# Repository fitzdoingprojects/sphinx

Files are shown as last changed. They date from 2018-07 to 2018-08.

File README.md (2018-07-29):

# sphinx
Sphinx

## Design Requirements
* Powered from 12V, last minimum one night on charge
* 24 LED Buttons (2 sets of 12)
* Audio Playback with Amplified Sound
* Water and Dust Resistant

## Major Components
* MCU - Teensy 3.6
* Buttons - Momentary Metal Push Buttons
* Sound - Speakers, (amplifier?), Sound Playback Controller
* Power - 12V Battery, step-down converters
* Enclosures - Dust/Water Proof, either acrylic or wood
* Cabling - ???

## Questions
* Buttons are momentary? Size requirements? LED color?
	white, 16mm
* Is there already a battery to use?
	or 12v
* Are there already speakers to use?
	get amazon
* How far are buttons from main controller?
* How far apart are buttons from each other?
* What type of mounting structure is available for main controller?
* Should we bring back-ups of components, if so which ones and how many?

## Design Choices
* Exact button type (see BOM)
* Cabling
	* Should each button have a direct wire back to main controller, or should the main controller route to each fin and then seprate wiring to each button.
	* Use pre-made cables (e.g ethernet cable rj45 to each button, or Parallel Port IEEE 1284 cable to each fin), or custom made cables?
* Speakers
	* Either self powered or amplifer plus unpowered speakers. 
	* How loud? 
	* Full range, or additional subwoofer?
* Power 
	* 12V battery, what size? 
	* How to charge?
* Enclosure
	* What type of material
	* How to mount

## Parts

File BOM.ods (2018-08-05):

Turtle Fortune Teller - Sphinx!
Component | Quantity | Cost | Description | Notes | Link
Teensy 3.6 | 1 | $29.25 | Main MCU |  | https://www.pjrc.com/store/teensy36.html
Audio Adapter Board for Teensy | 1 | $14.25 | Audio Playback controller | Supports up 32gb of files | https://www.pjrc.com/store/teensy3_audio.html
TL5940 | 2 | $2.00 | PWM LED controller | Supports 16 channels, daisy chainable. Works at 5V | http://www.ti.com/product/TLC5940
Buttons (Legitimate) | 27 | $5.00 | Momentary Push Button with LED |  | https://www.sparkfun.com/products/11967
12V to 5V – Converter | 1 | $5.00 | Buck Converter | I already have a couple lying around
Cables
RJ45 8x Port | 3 | $11.00 | Connection Port on main board for 24 buttons/leds |  | https://www.digikey.com/product-detail/en/pulse-electronics-network/E5908-5VC145-L/553-2267-ND/4868937
RJ45 250ft | 1 | $30.00 | RJ45 cable that can be cut to length |  | https://www.monoprice.com/product?p_id=13677
RJ45 Plugs | 2 | $6.00 | Plugs on end of each cable |  | https://www.monoprice.com/product?p_id=7322
RJ45 Strain Relief | 2 | $1.50 | Strain Relief for each Cable |  | https://www.monoprice.com/product?c_id=105&cp_id=10513&cs_id=1051306&p_id=7248&seq=1&format=2
Dust Caps | 3 | $1.00 | Dust Caps for Main board port when cables not connected |  | https://www.ebay.com/itm/Ethernet-Hub-Port-RJ45-Anti-Dust-Cover-Cap-Protector-Plug-10Pcs-Black-CP/332068478418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
Button Sockets | 30 | $1.00 | Sockets for 16” buttons | Requires pig-tie to ethenet cable | https://www.ebay.com/itm/5-Pin-Wire-Connector-Wiring-Socket-Plug-Adapter-For-16-19mm-Push-Button-Switch/272884697047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
Button to Ethernet | 6 | $5.00 | Way to connect Ethernet Cord to Button |  | https://www.adafruit.com/product/1152
Crimp Tool | 1 | $20.00 | Need to crimp cables |  | https://www.amazon.com/TRENDnet-RJ-45-RJ-12-RJ-11-TC-CT68/dp/B0000AZK4G/?tag=823814-20
wire glands
Possible Components
Self Powered Speakers | 1 | $49.13 | Waterproof Self Powered speakers | Set of 2. Alternatively could use unpowered speaker and amplifier. | https://www.amazon.com/Pyle-3-5-inch-Waterproof-Bluetooth-PLMR23BBT/dp/B06XCYDRB7?s=electronics
Battery | 1 | $36.98 | 12V 18Ah AGM battery | Any 12V battery with >10Ah should last the a whole night. | https://www.amazon.com/ExpertPower-EXP12180-Rechargeable-Battery-Bolts/dp/B00A82A3RK?s=electronics
Buttons (China) | 24 | $2.00 | Momentary Push Button with LED | Chinisium | https://www.ebay.com/itm/3Pcs-12mm-3V-LED-Metal-Momentary-Push-Button-Switch-1NO-4Pin-Red-Green-Blue/182232000915
Cables | ??? | $20-50 | Not sure of best cable routing
Through Hole Button mounts | 120 | $0.18 | Could make custom board to connect Buttons to Ethernet cables |  | https://www.digikey.com/product-detail/en/keystone-electronics/3534/36-3534-ND/303876
Ethernet Plug | 30 | $0.50 | Could make custom board to connect Buttons to Ethernet cables |  | https://www.digikey.com/product-detail/en/amphenol-fci/54602-908LF/609-1046-ND/1001360
Other Costs
PCB | 1-3 | $5 each plus shipping | Will need one main board, and possibly one distribution board per fin
Small Components | ??? | $20.00 | I might need to order some other electronics components
Enclosures | 1-3 | $20-50 | Need to make dusty/water resistant enclosures for electronics
PURCHASED SO FAR
Component | Quantity | Cost | Date | From
Button to Ethernet | 30 | $1.00 | 07/12/18 | EBAY
MCU + Audio Controller |  | $65.64 | 07/12/18 | PJRC (Teensy)
Buttons | 27 | $139.67 | 07/26/18 | SparkFun
IP67 RJ-45 FeedThrough cable gland - Field Install 10 pack CG-RJ RJ-FT | 30 | 34.8 | 07/29/18 | ebat
heat shirink
0.11” terminals
digikey/arrow/lcsc orders

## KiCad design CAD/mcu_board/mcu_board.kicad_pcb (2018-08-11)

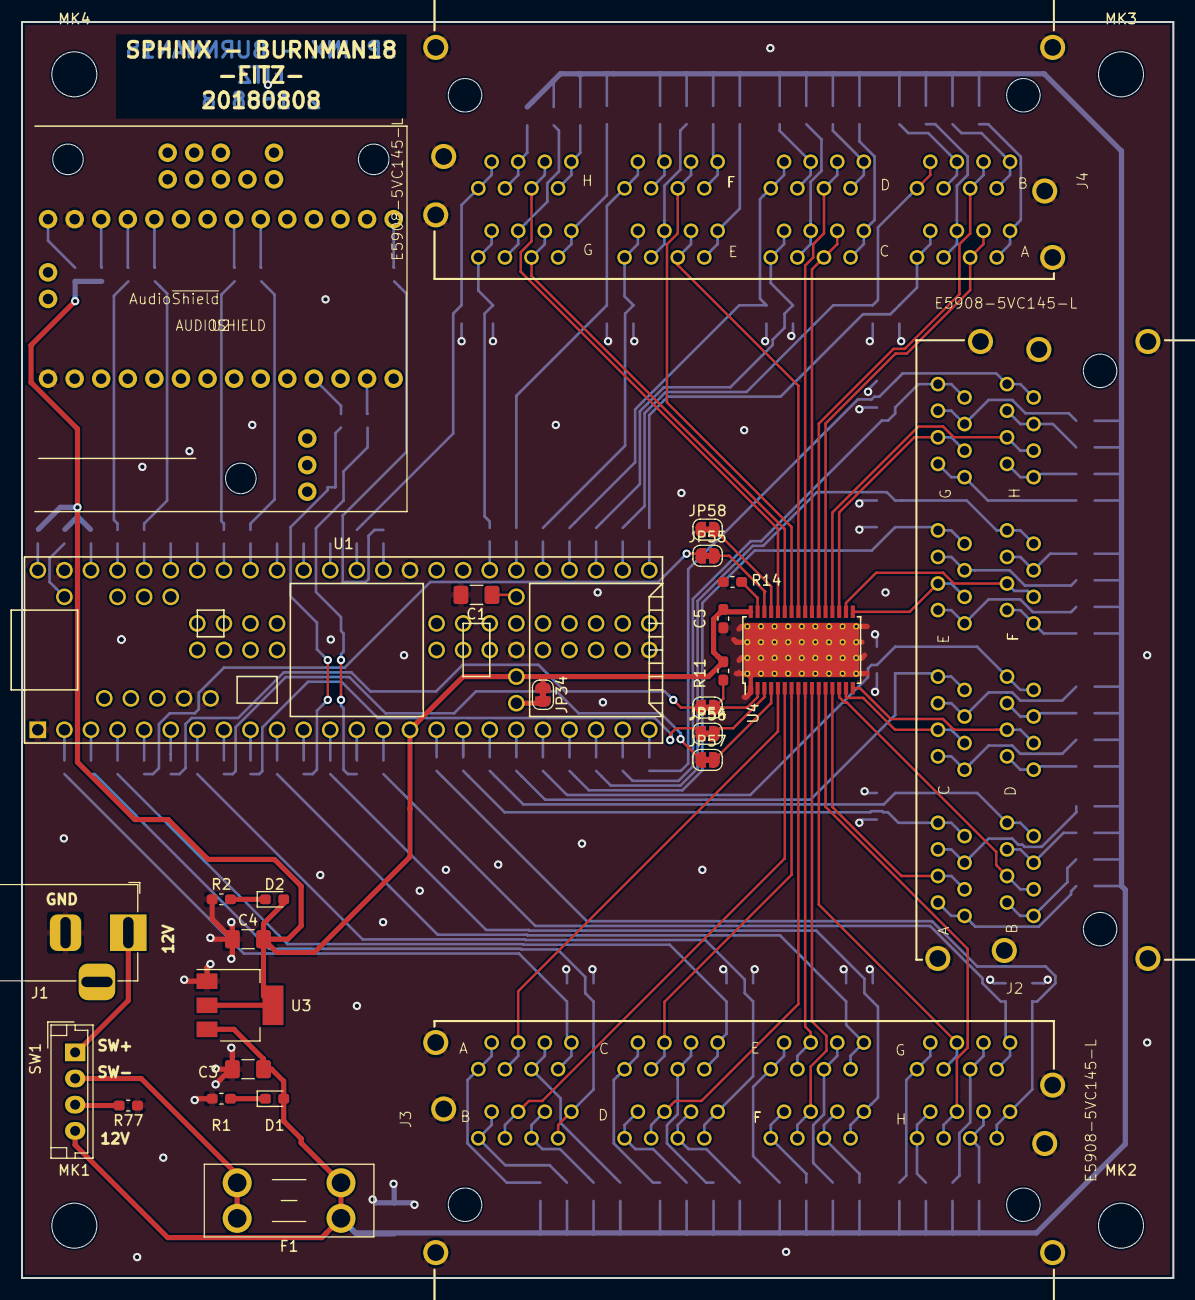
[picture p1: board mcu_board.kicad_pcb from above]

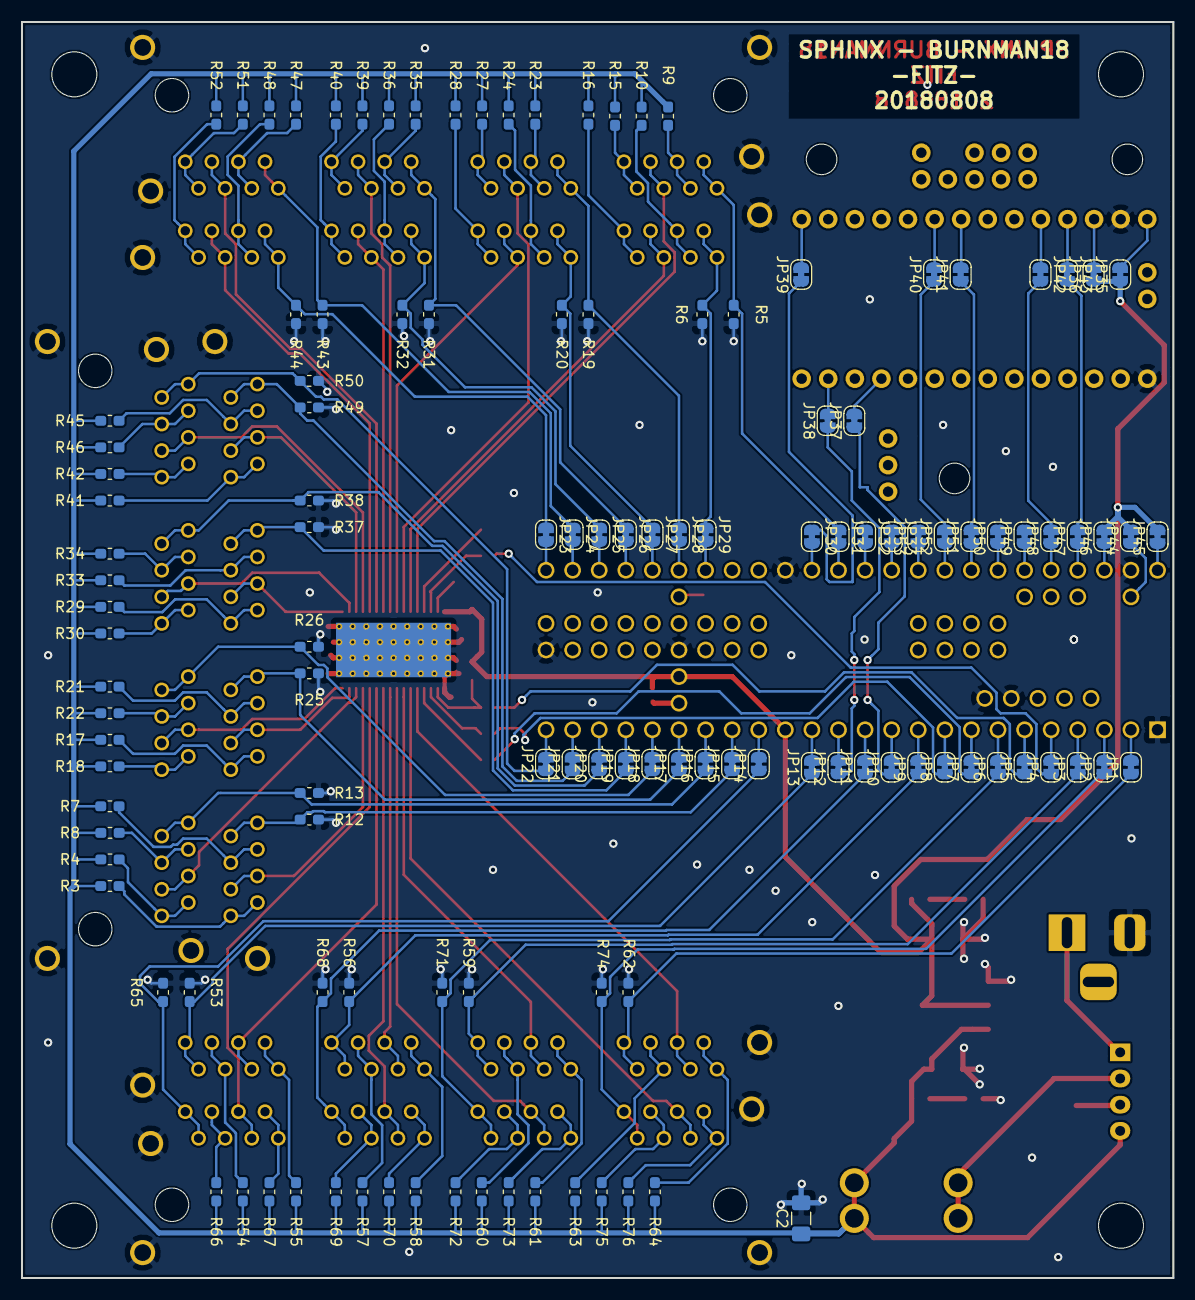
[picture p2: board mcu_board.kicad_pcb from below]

Board: 2 copper layers, 110.0 x 120.0 mm, 156 parts (125 on the bottom side), 175 nets.

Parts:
C1: 0.1uF; C_1206_3216Metric_Pad1.42x1.75mm_HandSolder
C2, C3: 22uF; C_1206_3216Metric_Pad1.42x1.75mm_HandSolder
C4: C_Small; C_1206_3216Metric_Pad1.42x1.75mm_HandSolder
C5: 0.1uF; C_0603_1608Metric_Pad1.05x0.95mm_HandSolder
D1, D2: LED_Small; LED_0603_1608Metric_Pad1.05x0.95mm_HandSolder
F1: Fuse_5A; Fuseholder_Blade_Mini_Keystone_3568
J1: 2.1MM BARREL; BarrelJack_Horizontal
J2, J3, J4: E5908-5VC145-L; PULSE_E5908-5VC145-L
JP1, JP2, JP3, JP4, JP5, JP6, JP7, JP8, JP9, JP10, JP11, JP12, JP13, JP14, JP15, JP16, JP17, JP18, JP19, JP20, JP21, JP22, JP23, JP24, JP25, JP26, JP27, JP28, JP29, JP30, JP31, JP32, JP33, JP34, JP35, JP36, JP37, JP38, JP39, JP40, JP41, JP42, JP43, JP44, JP45, JP46, JP47, JP48, JP49, JP50, JP51, JP52, JP53: Jumper_NO_Small; SolderJumper-2_P1.3mm_Bridged_RoundedPad1.0x1.5mm
JP54, JP55, JP56, JP57, JP58: Jumper_NC_Small; SolderJumper-2_P1.3mm_Bridged_RoundedPad1.0x1.5mm
MK1, MK2, MK3, MK4: Mounting_Hole; MountingHole_4.3mm_M4
R1, R2, R11, R14: 10K; R_0603_1608Metric_Pad1.05x0.95mm_HandSolder
R3, R4, R5, R6, R12, R13, R16, R17, R18, R19, R20, R25, R26, R28, R29, R31, R32, R37, R38, R39, R40, R41, R43, R44, R49, R50, R51, R52, R53, R55, R56, R58, R59, R61, R62, R64, R65, R68, R70, R71, R73, R74, R76, R77: 1K; R_0603_1608Metric_Pad1.05x0.95mm_HandSolder
R7, R8, R9, R10, R21, R22, R23, R24, R33, R34, R35, R36, R45, R46, R47, R48, R54, R57, R60, R63, R66, R69, R72, R75: 2.7K; R_0603_1608Metric_Pad1.05x0.95mm_HandSolder
R15, R27, R30, R42, R67: R_L; R_0603_1608Metric_Pad1.05x0.95mm_HandSolder
SW1: SW_SPST_LED; JST_EH_B04B-EH-A_1x04_P2.50mm_Vertical
U1: Teensy3.6; Teensy35_36
U2: AUDIOSHIELD
U3: LM1117-ADJ; SOT-223-3_TabPin2
U4: TLC5947DAP; HTSSOP-32-1EP_6.1x11mm_P0.65mm_EP5.2x11mm_Mask4.11x4.36mm_T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

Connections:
+3V3: C4.2, C5.1, D2.2, JP34.1, JP35.1, JP36.1, JP44.2, JP45.2, JP46.2, R11.2, U1.15, U1.26, U3.2, U4.32
+12V: C2.1, C3.1, D1.2, F1.1, R3.2, R4.2, R7.1, R8.1, R9.1, R10.1, R15.2, R16.2, R17.2, R18.2, R21.1, R22.1, R23.1, R24.1, R27.2, R28.2, R29.2, R30.2, R33.1, R34.1, R35.1, R36.1, R39.2, R40.2, R41.2, R42.2, R45.1, R46.1, R47.1, R48.1, R51.2, R52.2, R54.1, R55.2, R57.1, R58.2, R60.1, R61.2, R63.1, R64.2, R66.1, R67.2, R69.1, R70.2, R72.1, R73.2, R75.1, R76.2, SW1.4, U3.3
/AUDIO_BCLK: JP10.1, JP37.1
/AUDIO_LRCLK: JP43.2, JP47.2
/AUDIO_MCLK: JP12.1, JP38.1
/AUDIO_RX: JP30.1, JP39.1
/AUDIO_SCL: JP41.1, JP51.2
/AUDIO_SDA: JP40.1, JP52.2
/AUDIO_TX: JP42.2, JP48.2
/BLANK: JP5.1, JP54.1
/LED_0: J4.A5, J4.A6, U4.21
/LED_1: J4.B3, J4.B4, U4.22
/LED_2: J4.C5, J4.C6, U4.23
/LED_3: J4.D3, J4.D4, U4.24
/LED_4: J4.E5, J4.E6, U4.25
/LED_5: J4.F3, J4.F4, U4.26
/LED_6: J4.G5, J4.G6, U4.27
/LED_7: J4.H3, J4.H4, U4.28
/LED_8: J2.A5, J2.A6, U4.13
/LED_9: J2.B3, J2.B4, U4.14
/LED_10: J2.C5, J2.C6, U4.15
/LED_11: J2.D3, J2.D4, U4.16
/LED_12: J2.E5, J2.E6, U4.17
/LED_13: J2.F3, J2.F4, U4.18
/LED_14: J2.G5, J2.G6, U4.19
/LED_15: J2.H3, J2.H4, U4.20
/LED_16: J3.A5, J3.A6, U4.5
/LED_17: J3.B3, J3.B4, U4.6
/LED_18: J3.C5, J3.C6, U4.7
/LED_19: J3.D3, J3.D4, U4.8
/LED_20: J3.E5, J3.E6, U4.9
/LED_21: J3.F3, J3.F4, U4.10
/LED_22: J3.G5, J3.G6, U4.11
/LED_23: J3.H3, J3.H4, U4.12
/SCLK: JP8.1, JP56.1
/SIN: JP7.1, JP57.1
/SW_0: J4.A1, J4.A2, JP23.1, R44.2
/SW_1: J4.B7, J4.B8, JP24.1, R43.2
/SW_2: J4.C1, J4.C2, JP25.1, R32.2
/SW_3: J4.D7, J4.D8, JP26.1, R31.2
/SW_4: J4.E1, J4.E2, JP27.1, R20.2
/SW_5: J4.F7, J4.F8, JP28.1, R19.2
/SW_6: J4.G1, J4.G2, JP29.1, R6.2
/SW_7: J4.H7, J4.H8, JP31.1, R5.2
/SW_8: J2.A1, J2.A2, JP15.1, R12.2
/SW_9: J2.B7, J2.B8, JP16.1, R13.2
/SW_10: J2.C1, J2.C2, JP17.1, R25.2
/SW_11: J2.D7, J2.D8, JP18.1, R26.2
/SW_12: J2.E1, J2.E2, JP19.1, R37.2
/SW_13: J2.F7, J2.F8, JP20.1, R38.2
/SW_14: J2.G1, J2.G2, JP21.1, R49.2
/SW_15: J2.H7, J2.H8, JP22.1, R50.2
/SW_16: J3.A1, J3.A2, JP1.1, R62.2
/SW_17: J3.B7, J3.B8, JP2.1, R74.2
/SW_18: J3.C1, J3.C2, JP3.1, R59.2
/SW_19: J3.D7, J3.D8, JP6.1, R71.2
/SW_20: J3.E1, J3.E2, JP9.1, R56.2
/SW_21: J3.F7, J3.F8, JP11.1, R68.2
/SW_22: J3.G1, J3.G2, JP13.1, R53.2
/SW_23: J3.H7, J3.H8, JP14.1, R65.2
/XLAT: JP4.1, JP55.1
GND: C1.2, C2.2, C3.2, C4.1, C5.2, J1.2, J2.P1, J2.P2, J2.P3, J2.P4, J2.P5, J2.P6, J3.P1, J3.P2, J3.P3, J3.P4, J3.P5, J3.P6, J4.P1, J4.P2, J4.P3, J4.P4, J4.P5, J4.P6, R1.1, R2.1, R5.1, R6.1, R12.1, R13.1, R14.1, R19.1, R20.1, R25.1, R26.1, R31.1, R32.1, R37.1, R38.1, R43.1, R44.1, R49.1, R50.1, R53.1, R56.1, R59.1, R62.1, R65.1, R68.1, R71.1, R74.1, R77.1, U1.1, U1.27, U1.39, U1.52, U1.61, U1.62, U1.74, U2.G, U2.GND, U3.1, U4.1, U4.33
unnamed: C1.1, U1.29
unnamed: D1.1, R1.2
unnamed: D2.1, R2.2
unnamed: F1.2, SW1.2
unnamed: J1.1, SW1.1
unnamed: J2.A3, J2.A4, R7.2
unnamed: J2.A7, J2.A8, R3.1
unnamed: J2.B1, J2.B2, R4.1
unnamed: J2.B5, J2.B6, R8.2
unnamed: J2.C3, J2.C4, R21.2
unnamed: J2.C7, J2.C8, R17.1
unnamed: J2.D1, J2.D2, R18.1
unnamed: J2.D5, J2.D6, R22.2
unnamed: J2.E3, J2.E4, R33.2
unnamed: J2.E7, J2.E8, R29.1
unnamed: J2.F1, J2.F2, R30.1
unnamed: J2.F5, J2.F6, R34.2
unnamed: J2.G3, J2.G4, R45.2
unnamed: J2.G7, J2.G8, R41.1
unnamed: J2.H1, J2.H2, R42.1
unnamed: J2.H5, J2.H6, R46.2
unnamed: J3.A3, J3.A4, R63.2
unnamed: J3.A7, J3.A8, R64.1
unnamed: J3.B1, J3.B2, R76.1
unnamed: J3.B5, J3.B6, R75.2
unnamed: J3.C3, J3.C4, R60.2
unnamed: J3.C7, J3.C8, R61.1
unnamed: J3.D1, J3.D2, R73.1
unnamed: J3.D5, J3.D6, R72.2
unnamed: J3.E3, J3.E4, R57.2
unnamed: J3.E7, J3.E8, R58.1
unnamed: J3.F1, J3.F2, R70.1
unnamed: J3.F5, J3.F6, R69.2
unnamed: J3.G3, J3.G4, R54.2
unnamed: J3.G7, J3.G8, R55.1
unnamed: J3.H1, J3.H2, R67.1
unnamed: J3.H5, J3.H6, R66.2
unnamed: J4.A3, J4.A4, R48.2
unnamed: J4.A7, J4.A8, R52.1
unnamed: J4.B1, J4.B2, R51.1
unnamed: J4.B5, J4.B6, R47.2
unnamed: J4.C3, J4.C4, R36.2
unnamed: J4.C7, J4.C8, R40.1
unnamed: J4.D1, J4.D2, R39.1
unnamed: J4.D5, J4.D6, R35.2
unnamed: J4.E3, J4.E4, R24.2
unnamed: J4.E7, J4.E8, R28.1
unnamed: J4.F1, J4.F2, R27.1
unnamed: J4.F5, J4.F6, R23.2
unnamed: J4.G3, J4.G4, R10.2
unnamed: J4.G7, J4.G8, R16.1
unnamed: J4.H1, J4.H2, R15.1
unnamed: J4.H5, J4.H6, R9.2
unnamed: JP1.2, U1.2
unnamed: JP2.2, U1.3
unnamed: JP3.2, U1.4
unnamed: JP4.2, U1.5
unnamed: JP5.2, U1.6
unnamed: JP6.2, U1.7
unnamed: JP7.2, U1.8
unnamed: JP8.2, U1.9
unnamed: JP9.2, U1.10
unnamed: JP10.2, U1.11
unnamed: JP11.2, U1.12
unnamed: JP12.2, U1.13
unnamed: JP13.2, U1.14
unnamed: JP14.2, U1.16
unnamed: JP15.2, U1.17
unnamed: JP16.2, U1.18
unnamed: JP17.2, U1.19
unnamed: JP18.2, U1.20
unnamed: JP19.2, U1.21
unnamed: JP20.2, U1.22
unnamed: JP21.2, U1.23
unnamed: JP22.2, U1.24
unnamed: JP23.2, U1.30
unnamed: JP24.2, U1.31
unnamed: JP25.2, U1.32
unnamed: JP26.2, U1.33
unnamed: JP27.2, U1.34
unnamed: JP28.2, U1.35
unnamed: JP29.2, U1.36
unnamed: JP30.2, U1.40
unnamed: JP31.2, U1.41
unnamed: JP32.2, U1.42
unnamed: JP33.2, U1.43
unnamed: JP34.2, U1.25
unnamed: JP35.2, U2.5V
unnamed: JP36.2, U2.3V
unnamed: JP37.2, U2.9
unnamed: JP38.2, U2.11
unnamed: JP39.2, U2.13
unnamed: JP40.2, U2.18
unnamed: JP41.2, U2.19
unnamed: JP42.1, U2.22
unnamed: JP43.1, U2.23
unnamed: JP44.1, U1.54
unnamed: JP45.1, U1.53
unnamed: JP46.1, U1.51
unnamed: JP47.1, U1.50
unnamed: JP48.1, U1.49
unnamed: JP49.1, U1.48
unnamed: JP50.1, U1.47
unnamed: JP51.1, U1.46
unnamed: JP52.1, U1.45
unnamed: JP53.1, U1.44
unnamed: JP54.2, R11.1, U4.2
unnamed: JP55.2, U4.30
unnamed: JP56.2, U4.3
unnamed: JP57.2, U4.4
unnamed: JP58.2, U4.29
unnamed: R14.2, U4.31
unnamed: R77.2, SW1.3

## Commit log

2018-07-12 adds BOM and updates README
    [BOM.ods]
2018-07-13 updated BOM
    [BOM.ods]
2018-07-29 adds KiCAD files
    [mcu_board.kicad_pcb, mcu_board.sch]
2018-07-30 completes most wiring for MCU
    [BOM.ods, mcu_board.sch]
2018-08-05 adds libs and firmwares
    [BOM.ods, mcu_board.sch]
2018-08-08 updates layout
    [mcu_board.kicad_pcb, mcu_board.sch]
2018-08-09 finishes most routing
    [mcu_board.kicad_pcb, mcu_board.sch]
2018-08-09 finish all routing but GND
    [mcu_board.kicad_pcb, mcu_board.sch]
2018-08-11 FINAL COMMIT FOR GERBERS 180808
    [mcu_board-B.Cu.gbl, mcu_board-B.Mask.gbs, mcu_board-B.SilkS.gbo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]
